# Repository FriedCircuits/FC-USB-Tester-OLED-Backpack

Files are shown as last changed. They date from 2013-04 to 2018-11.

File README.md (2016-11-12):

FC-USB-Tester-OLED-Backpack
===========================
This is the source code for the USB Tester OLED Backpack 

Which can be found at:
https://friedcircuits.us/tools/46

To compile this code you will need the following libraries:
===========================
Old Version

[Adafruit GFX](https://github.com/adafruit/Adafruit-GFX-Library)

[Adafruit SSD1306](https://github.com/adafruit/Adafruit_SSD1306)

2.0

Needs [UG8LIB] (https://github.com/olikraus/u8glib)

Both Versions

[TimerOne](https://github.com/PaulStoffregen/TimerOne)

[ClickButton](http://code.google.com/p/clickbutton/)

[Adafruit INA219](https://github.com/adafruit/Adafruit_INA219)

Download ZIP in each version folder for a working set with libraries and configuration of hardware SPI and display size

Use the new firmware version with the new Java app

https://github.com/FriedCircuits/FC-USB-Tester-Data-Logger-App

There may be a bug that shifts the display. We are working on a solution - Testing a new library for the display.

How to update firmware:

http://friedcircuits.us/docs/oled-backpack-how-to-update-firmware/

License: All source code and designs are released under 

Creative Commons NonCommercial-ShareAlike 

CC BY-NC-SA



Please contact me for commercial opportunities.

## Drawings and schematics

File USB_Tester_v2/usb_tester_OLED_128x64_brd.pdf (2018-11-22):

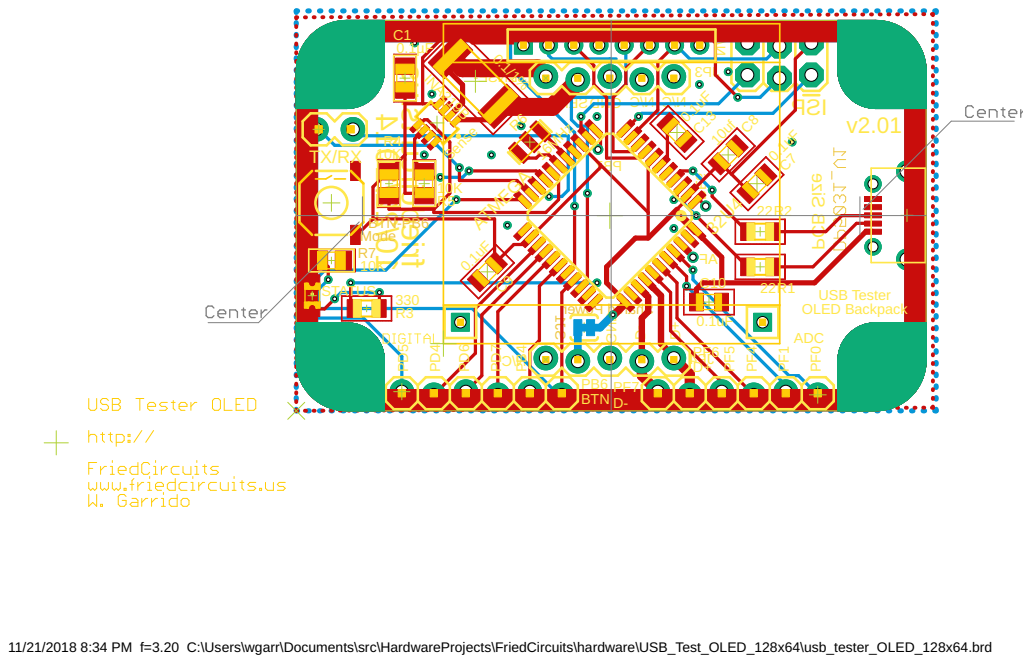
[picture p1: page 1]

11/21/2018 8:34 PM f=3.20 C:\Users\wgarr\Documents\src\HardwareProjects\FriedCircuits\hardware\USB_Test_OLED_128x64\usb_tester_OLED_128x64.brd

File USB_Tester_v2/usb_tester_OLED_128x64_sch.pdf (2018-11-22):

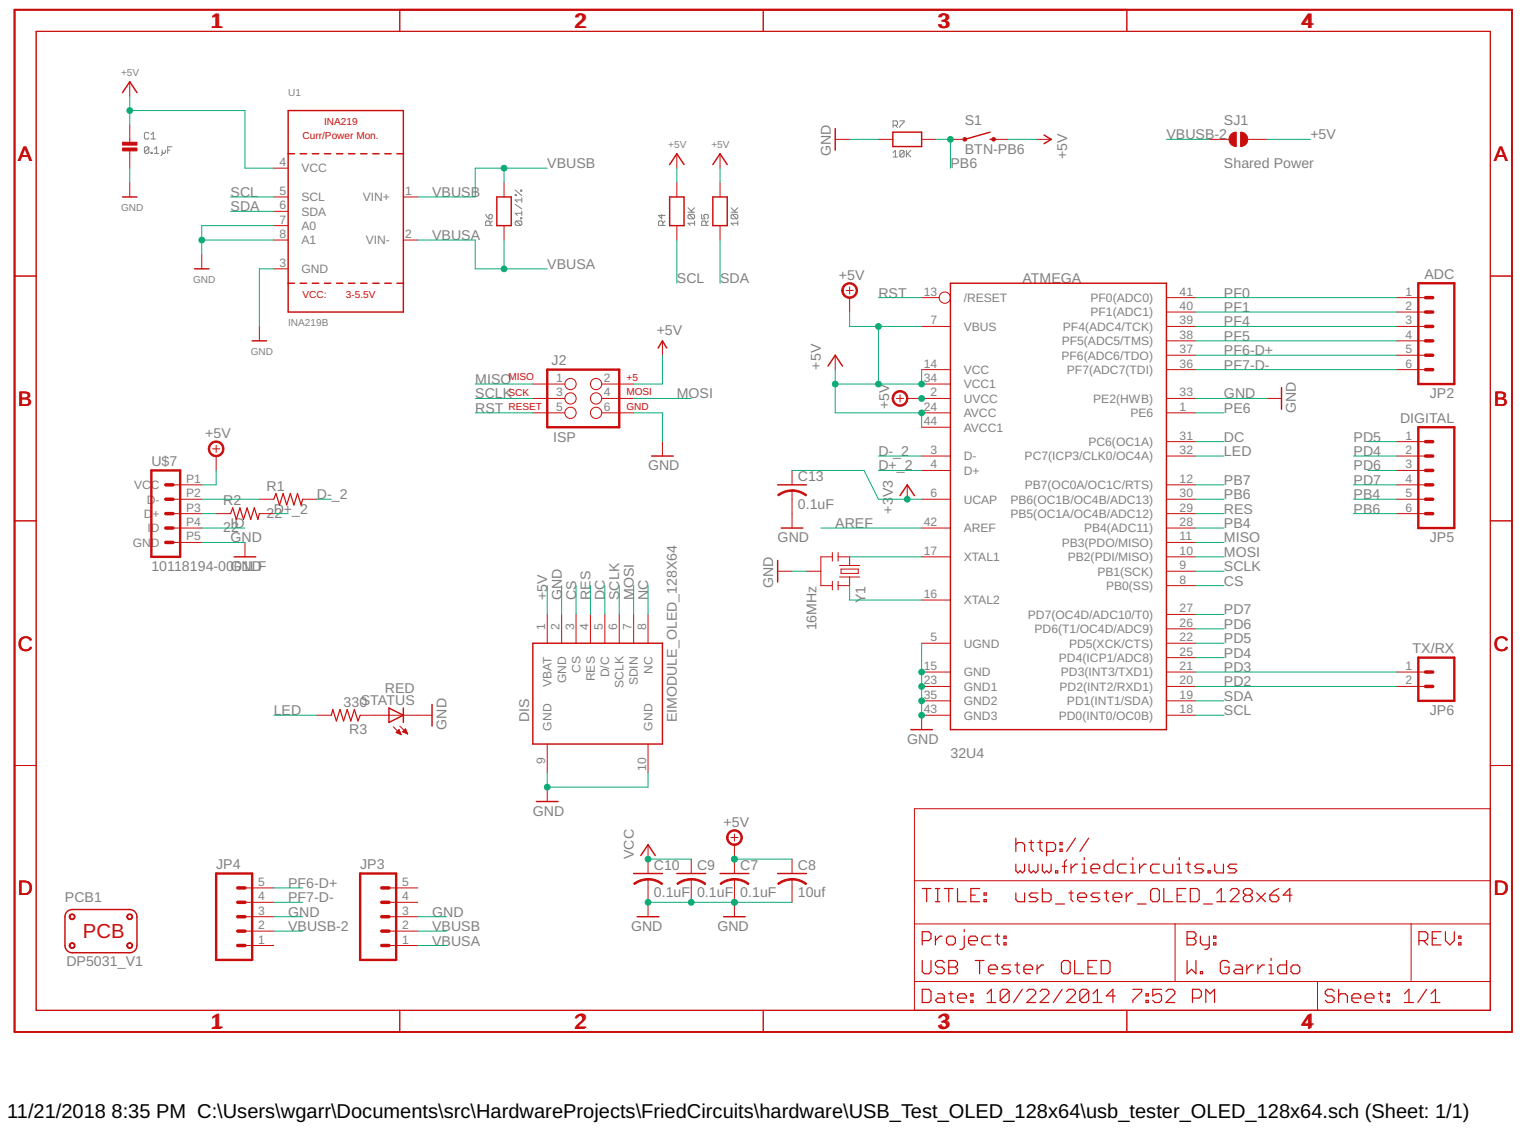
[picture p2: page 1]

11/21/2018 8:35 PM C:\Users\wgarr\Documents\src\HardwareProjects\FriedCircuits\hardware\USB_Test_OLED_128x64\usb_tester_OLED_128x64.sch (Sheet: 1/1)

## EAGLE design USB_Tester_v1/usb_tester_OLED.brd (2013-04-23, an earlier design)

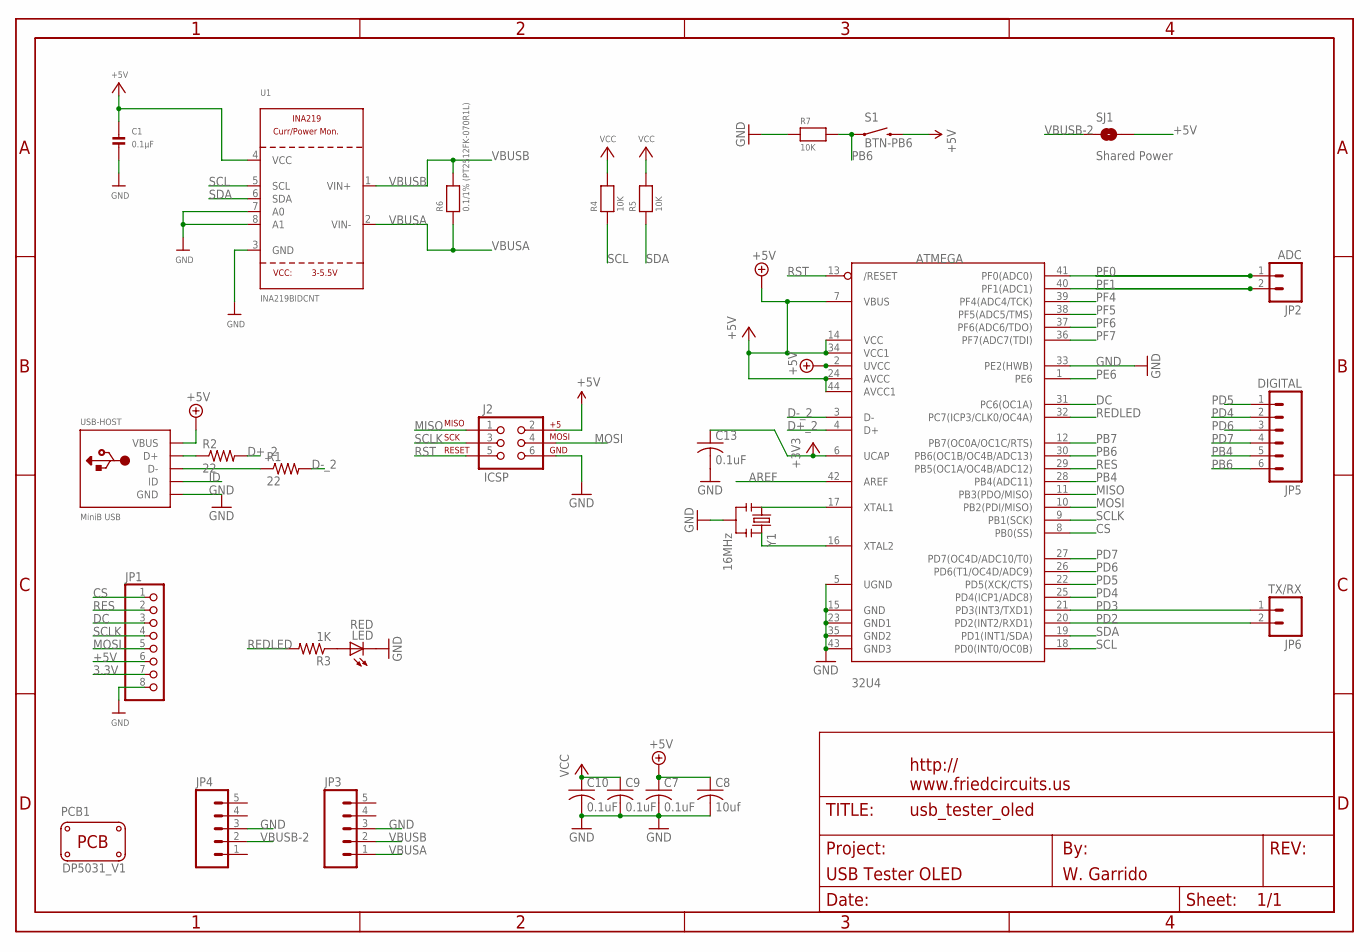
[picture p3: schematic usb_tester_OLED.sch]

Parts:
32U4: ATMEGA; TQFP44
C1: 0.1µF; 0805
C7, C9, C10, C13: 0.1uF; C0805K
C8: 10uf; C0805K
J2: ICSP; 2X3_LOCK
JP1: HEADER-1X876MIL; 1X08_ROUND_76
JP2: ADC; 1X02_LOCK
JP3, JP4: M05LOCK; 1X05_LOCK
JP5: DIGITAL; 1X06_LOCK
JP6: TX/RX; 1X02_LOCK
LED: RED; CHIPLED_0805
PCB1: PCB_DP_RECTANGLE-31X50; DP5031_V1
R1, R2: 22; R0805
R3: 1K; R0805
R4, R5, R7: 10K; 0805
R6: 0.1/1% (PT2512FK-070R1L); 2512
S1: BTN-PB6; TACTILE_SWITCH_SMD
SJ1: Shared Power; SJ_2S-TRACE
U1: INA219BIDCNT; SOT23-8
U$1: FRAME_DINA4_L; FC_CREDIT
USB-HOST: MiniB USB; USB-MINIB
Y1: 16MHz; RESONATOR-SMD

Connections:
3.3V: JP1.7
+3V3: 32U4.6 (UCAP), C13.1
+5V: 32U4.2 (UVCC), 32U4.7 (VBUS), 32U4.14 (VCC), 32U4.24 (AVCC), 32U4.34 (VCC1), 32U4.44 (AVCC1), C1.1, C7.1, C8.1, C9.1, C10.1, J2.2, JP1.6, R4.2, R5.2, S1.3 (2), SJ1.2, U1.4 (VCC), USB-HOST.VBUS
AREF: 32U4.42 (AREF)
CS: 32U4.8 (PB0(SS)), JP1.1
D+_2: 32U4.4 (D+), R2.2
D-_2: 32U4.3 (D-), R1.2
DC: 32U4.31 (PC6(OC1A)), JP1.3
GND: 32U4.5 (UGND), 32U4.15 (GND), 32U4.23 (GND1), 32U4.33 (PE2(HWB)), 32U4.35 (GND2), 32U4.43 (GND3), C1.2, C7.2, C8.2, C9.2, C10.2, C13.2, J2.6, JP1.8, JP3.3, JP4.3, LED.C, R7.1, U1.3 (GND), U1.7 (A0), U1.8 (A1), USB-HOST.GND, Y1.2
ID: USB-HOST.ID
MISO: 32U4.11 (PB3(PDO/MISO)), J2.1
MOSI: 32U4.10 (PB2(PDI/MISO)), J2.4, JP1.5
unnamed: LED.A, R3.1
unnamed: R2.1, USB-HOST.D+
unnamed: R1.1, USB-HOST.D-
unnamed: 32U4.17 (XTAL1), Y1.1
unnamed: 32U4.16 (XTAL2), Y1.3
PB4: 32U4.28 (PB4(ADC11)), JP5.5
PB6: 32U4.30 (PB6(OC1B/OC4B/ADC13)), JP5.6, R7.2, S1.1
PB7: 32U4.12 (PB7(OC0A/OC1C/RTS))
PD2: 32U4.20 (PD2(INT2/RXD1)), JP6.2
PD3: 32U4.21 (PD3(INT3/TXD1)), JP6.1
PD4: 32U4.25 (PD4(ICP1/ADC8)), JP5.2
PD5: 32U4.22 (PD5(XCK/CTS)), JP5.1
PD6: 32U4.26 (PD6(T1/OC4D/ADC9)), JP5.3
PD7: 32U4.27 (PD7(OC4D/ADC10/T0)), JP5.4
PE6: 32U4.1 (PE6)
PF0: 32U4.41 (PF0(ADC0)), JP2.1
PF1: 32U4.40 (PF1(ADC1)), JP2.2
PF4: 32U4.39 (PF4(ADC4/TCK))
PF5: 32U4.38 (PF5(ADC5/TMS))
PF6: 32U4.37 (PF6(ADC6/TDO))
PF7: 32U4.36 (PF7(ADC7(TDI))
REDLED: 32U4.32 (PC7(ICP3/CLK0/OC4A)), R3.2
RES: 32U4.29 (PB5(OC1A/OC4B/ADC12)), JP1.2
RST: 32U4.13 (/RESET), J2.5
SCL: 32U4.18 (PD0(INT0/OC0B)), R4.1, U1.5 (SCL)
SCLK: 32U4.9 (PB1(SCK)), J2.3, JP1.4
SDA: 32U4.19 (PD1(INT1/SDA)), R5.1, U1.6 (SDA)
VBUSA: JP3.1, R6.1, U1.2 (VIN-)
VBUSB: JP3.2, R6.2, U1.1 (VIN+)
VBUSB-2: JP4.2, SJ1.1

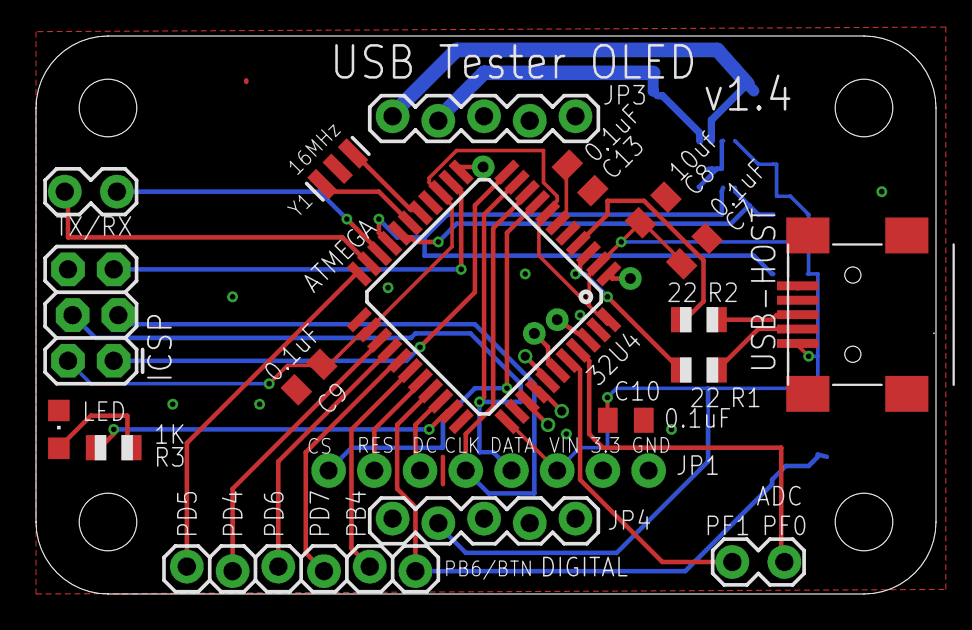
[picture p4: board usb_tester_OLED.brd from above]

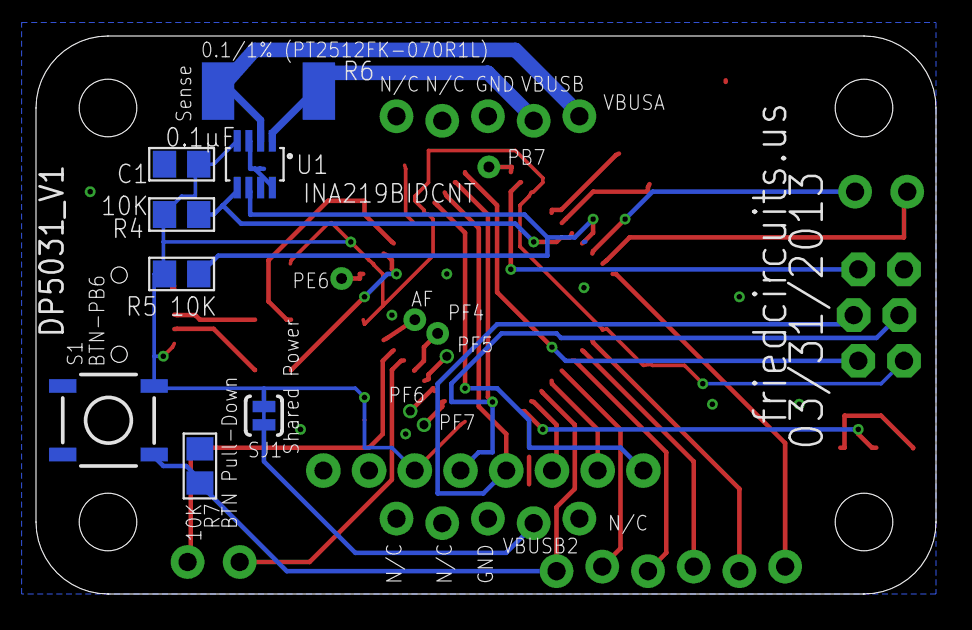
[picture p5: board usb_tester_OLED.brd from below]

Board: 2 copper layers, 50.0 x 31.0 mm, 29 parts (8 on the bottom side), 33 nets.

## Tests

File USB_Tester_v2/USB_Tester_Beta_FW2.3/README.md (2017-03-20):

FC-USB-Tester-OLED-Backpack
===========================
This is the beta firmware v2.2 for the USB Tester OLED Backpack. 

Can be found at:
https://friedcircuits.us/tools/46

New Features
===========================
Beta FW 2.2
* Cleaned up old code and added comment block to every function
* Added run timer, thanks to WeisTekEng
* Events Trigger serial notification of start and end of threshold and percent change
* Ability to save settings to EEPROM
* Ability to disable display for long term logging to save on wear
* New Commmands
	* E:0 - Disable events
	* E:1 - mA Threshold trigger - start and end uses existing W: command to set mA threshold
	* E:2 - Single percent changed
	* P:XXX - Set percent changed trigger
	* C:0 - Output current saved settings
	* C:1 - Load saved settings
	* C:2 - Save settings
	* C:3 - Output running settings
	* D:0 - Disable display
	* D:1 - Enable display

Hold button during boot to disable loading settings from EEPROM. 

Beta FW 2.3 - Code review help from @PhilipFreidin from fliptronics.com
* Increase sample speed default to 1kHz! This is a biggy feature, made possible by the following optimizations
* Increase I2C clock to 800kHz from 100kHz
* USB D+/- ADC uses int and ADC clock set to 250khz, a bit past recommended of 200khz
* Removed F() to free up flash and should be faster but uses 14% more RAM
* Fixed drawEnergy, wasn't using printjustifed2 so was rounding and displaying .00
* Using accumulators in readADC ISR and calculate in main loop mAh, mWh and current/voltage avg
* Optimize graph draw by moving mapping of values to drawGraph
* Optimize map function
* Reduce use of floats
* Libraries now included in source folder for portablity and customization of libraries
* Allow faster serial rate
* 2.31 fixed mAh/mWh calculations
* 2.32 optimized mAh/mWh calculations and var clean up
* TODO: Handle negative current for monitoring battery charging. 

28236 Bytes used
  436 Bytes free

Uses the following libraries:
===========================

[UG8LIB] (https://github.com/olikraus/u8glib)

[TimerOne](https://github.com/PaulStoffregen/TimerOne)

[ClickButton](http://code.google.com/p/clickbutton/)

[Adafruit INA219](https://github.com/adafruit/Adafruit_INA219)

[EEPROMex] (https://github.com/thijse/Arduino-EEPROMEx)

Firmware can be used with Wizkers.io 

Firmware Update
==============================

Wizkers.io - Download and select hex from Intrument Upgrade under settings.

Hex can be loaded with AVRDUDE as well. 

Arduino IDE: http://friedcircuits.us/docs/oled-backpack-how-to-update-firmware/

License: All source code and designs are released under 

Creative Commons NonCommercial-ShareAlike 

CC BY-NC-SA



Please contact me for commercial opportunities.

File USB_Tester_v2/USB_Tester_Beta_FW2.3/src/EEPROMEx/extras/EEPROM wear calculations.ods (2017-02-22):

EEPROM wear calculations
We will assume | 100,000 | write/erase cycles
From livetime to writes /second
If we want our EEPROM to live for | 100 | years
we could write | 1000 | times per cell per year
which is equal to | 2.74 | times per cell per day
which is equal to | 0.11 | times per cell per hour
which is equal to | 0.002 | times per cell per minute
which is equal to | 0.0000 | times per cell per second
From spread to writes/ second
However, if we spread a byte over | 200 | cells
we can write this byte | 22.83 | times per hour
which is equal to | 0.38 | times per minute
From time / write to livetime
We want to write once per | 1.000 | millisec
we could write for | 100000 | seconds
which is equal to | 1666.67 | minutes
which is equal to | 27.78 | hours
which is equal to | 1.157 | Days

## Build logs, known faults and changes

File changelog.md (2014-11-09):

FC-USB-Tester-OLED-Backpack
===========================
v2.10
-Start of changelog

-Switch to UG8Lib display library

-Clean up Energy and Peak\Mins screens

-Updated large font screens with bar graphs that auto scale

-Added firmware version with serial command

Note: Java app v1.0+ can check for new versions of the firmware from github

License: All source code and designs are released under 

Creative Commons NonCommercial-ShareAlike 

CC BY-NC-SA



Please contact me for commercial opportunities.

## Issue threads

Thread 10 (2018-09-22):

Auto reset when plug in DUT

gyboy, 2018-09-22:
hi, I have to say this tool is so useful,but I found some problems when using it, usually when the the dut was pluged in the deviceafter it had power on(especially comsumes heavy current), the device will auto reset while I can see the boot led is breath and then display the first page. I have confirmed that it was not made by the voltage dropped down, I doubted that mabye the usb data line influenced the mcu while I did not found any influence inthe code,I do not know how to solve it,can you give me some advice,ths.

FriedCircuits, 2018-11-22:
Hi,
Sorry for the delay in getting back to you. I have seen this issue from time to time and never figured out what it was. Something is triggering the ATmega32u4 to enter the bootloader. I know that the way the bootloader is usually entered is to open the serial port at 1200 baud and then disconnect and reconnect to reprogram.  I thought it would be due to voltage drop but as you said it doesn't seem to be so.  What I have noticed it doesn't seem to do it twice in a row just the first time. So really strange.

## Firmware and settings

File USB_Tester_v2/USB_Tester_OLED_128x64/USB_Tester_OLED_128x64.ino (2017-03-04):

/*************************************
USB Tester OLED Display - v1.2
Created by: William Garrido
Created: 01/10/2013
This displays the current and voltage from the USB Tester to the OLED display using the OLED Backpack
Also sends data to serial port for data logging via Java app
Kits are aviaible at www.tindie.com and more info can be found on www.friedcircuits.us

Changelog by Edouard Lafargue

2013.04.11
- Autoscroll of graph

ToDo:
- Remove shunt voltage and load voltage display (are those really necessary ?)
- Autoscale of graph

-William Garrido
2013.08.17
-Removed SVolt and BVolt
-Moved Current\Volt under graph
-Extend graph width of display
-Use clearDisplay to speed up redraws
-Reduce logo display time
-Enabled button to cycle display speed
-Millis based delay

2013.08.27 - Edouard Lafargue
- Add simple graph autoscale (500mA, 1A, 1.5A, 2A, 5A)

2013.08.29 - Edouard Lafargue
- Use TimerOne interrupts to read values at a fixed rate, so that
  we can energy consumption
- New feature: multiple screens (ongoing)

2013.08.30 - Edouard Lafargue
- Display mA without decimal points

2013.09.09 - William Garrido
-Added decimal to lower display
-Top display auto adjust if decimal needed
-Turned off debug by default
-Long press clears peaks and energy usage

2013.09.10 - William Garrido
-Added system display message handling with display time
-Added Reset message
How to use setMsg()
Call setMsg(Message, time to display)
-Remove decimal due to inacurrate, IC is .8mA resolution
-fixed which voltage var for peak current tracking
-fixed min voltage\current reset

2013.09.11 - William Garrido
-Rewrote button function using ClickButton library from 
http://code.google.com/p/clickbutton/wiki/Usage
Fixes screen changing when reseting, 
so action happens after button is let go
-Added 2nd printJustified function for decimal
-Now mWh and mAh use decimals

2013.11.10 - Ed Lafargue
- Add support for basic serial commands
- Keep graph memory as unsigned ints instead of floats, saves 256 bytes in memory!

2014.01.12 - William Garrido
- Improve D-\+ Analog readings by using internal 1.1v ref and dividing by 1023 instead of 1024
- Split energy readings to multiple lines to take use of larger display and give room for larger readers

2014-10-10 - William Garrido
- Switch to UG8Lib for graphics handling
- Split update scope function, only updates graph. Graph data updates is outside picture loop.
- Spilt message handling so that variables are updated outside picture loop.
- Clean up code
- Added command to get firmware version

2014-11-10-2014 - William garrido
-Re-enable device name on startup
-Add firmware version to display startup
**************************************/

#include <Wire.h>
#include <SPI.h>
#include <Adafruit_INA219.h>
#include <U8glib.h>
#include <TimerOne.h>
#include <ClickButton.h>

#define FW_VERSION 2.11

// All hardware pin usage is defined here:
//#define OLED_DC 5
//#define OLED_CS SS
//#define OLED_CLK SCK
//#define OLED_MOSI MOSI
//#define OLED_RESET 9
#define LEDPIN 13
#define BTN_PIN 10
//USB Data Lines
#define USB_DP A1
#define USB_DM A0

// Define two set/clear macros to do PIN manipulation
// way way faster than Arduino's digitalWrite.
// inspired by the the _BV() macro
#define setpin(port, pin) (port) |= (1 << (pin)) 
#define clearpin(port, pin) (port) &= ~(1 << (pin))

#define DEBUG 0

uint16_t ledWarn = 400; //Threshold in mA

// Graph values:
// Graph area is from 0 to 127
#define GRAPH_MEMORY 128
// We store the values as unsigned 16 bit integers (0 to 65535), rather than floats,
// so that our array is only 256 bytes long, instead of 512 (floats are 32bits).
uint16_t graph_Mem[GRAPH_MEMORY];
uint8_t ring_idx = 0; // graph_Mem is managed as a ring buffer.

// Autoscale management
uint16_t autoscale_limits[] = {100, 200, 500, 1000, 1500, 2500, 3200}; // in mA
uint8_t autoscale_size = sizeof(autoscale_limits) / sizeof(uint16_t);
uint8_t graph_MAX = 0; // Max scale by default
float autoscale_max_reading = 0;  // The memorized maximum reading over the window
uint8_t autoscale_countdown = GRAPH_MEMORY;

//Button
ClickButton modeBtn(BTN_PIN, HIGH);

// Serial input buffer
#define INPUT_BUFFER_SIZE 16
char input_Buffer[INPUT_BUFFER_SIZE];
uint8_t input_Buffer_Index;

// Serial output management
unsigned long lastOutput = 0;
uint16_t serialOutputRate = 1000;

// On-screen output
unsigned long lastDisplay = 0;

//Current Sensor
Adafruit_INA219 ina219;

uint16_t OLED_REFRESH_SPEED = 100; //Startup refresh delay

uint8_t graphX = 0; //Start of X for graph
uint8_t graphY = 0;  //y placement of graph

//Init OLED Display
//Adafruit_SSD1306 display(OLED_MOSI, OLED_CLK, OLED_DC, OLED_RESET, OLED_CS);
U8GLIB_SSD1306_128X64 display(SS, 5, 9);
  
//FriedCircuits Logo for startup 
/*
static unsigned char FriedCircuitsUSBTester[] PROGMEM = 
{
0x00, 0x00, 0x00, 0x00, 0x00, 0x00, 0x00, 0x0F, 0x0F, 0x87, 0x87, 0xC0, 0x0C, 0x41, 0x86, 0x00,
0x00, 0x00, 0x00, 0x00, 0x00, 0x00, 0x00, 0x00, 0x00, 0x00, 0x00, 0x00, 0x0C, 0x41, 0x86, 0x00,
0x00, 0x00, 0x00, 0x00, 0x00, 0x00, 0x00, 0x00, 0x00, 0x00, 0x00, 0x00, 0x0C, 0x40, 0xCC, 0x70,
0xE1, 0xF0, 0xF0, 0xF8, 0x00, 0x00, 0x00, 0x00, 0x07, 0x00, 0x00, 0x00, 0x0C, 0x40, 0xFC, 0xF8,
0xF3, 0xF9, 0xF9, 0xFC, 0x00, 0x00, 0x00, 0x00, 0x0F, 0x80, 0x00, 0x00, 0x0C, 0x40, 0x31, 0xCC,
0x33, 0x1B, 0x1D, 0x8C, 0x00, 0x00, 0x00, 0x00, 0x18, 0xC0, 0x00, 0x00, 0x0C, 0x40, 0x01, 0x8C,
0x1A, 0x1B, 0x0D, 0x8C, 0x00, 0x07, 0xFF, 0xFF, 0xF8, 0xC0, 0x00, 0x00, 0x0C, 0x40, 0x01, 0x8C,
0x33, 0x1B, 0x99, 0x8C, 0x00, 0x1F, 0xFF, 0xFF, 0xF8, 0xC0, 0x00, 0x00, 0x0C, 0x40, 0x39, 0xFC,
0xF3, 0xF1, 0xF9, 0xF8, 0x00, 0x78, 0x00, 0x00, 0x1F, 0xC0, 0x00, 0x00, 0x0C, 0x40, 0xFC, 0xF8,
0xC0, 0xE0, 0xF0, 0x70, 0x01, 0xE0, 0x00, 0x00, 0x0F, 0x80, 0x00, 0x00, 0x0C, 0x40, 0xC6, 0x30,
0x00, 0x08, 0x00, 0x00, 0x0F, 0x80, 0x00, 0x00, 0x00, 0x00, 0x00, 0x00, 0x0C, 0x40, 0xC6, 0x30,
0x00, 0x0C, 0x00, 0x00, 0x3E, 0x00, 0x60, 0x00, 0x00, 0x00, 0x00, 0x00, 0x0C, 0x40, 0xC6, 0x30,
0x00, 0x1E, 0x00, 0x00, 0xF0, 0x01, 0xF8, 0x00, 0x00, 0x00, 0x00, 0x00, 0x0C, 0x40, 0xFE, 0x30,
0xFE, 0x1F, 0x1F, 0xFF, 0xC0, 0x01, 0x98, 0x00, 0x00, 0x00, 0x00, 0x00, 0x0C, 0x40, 0x7C, 0x30,
0xFE, 0x3F, 0x9F, 0xC0, 0x00, 0x00, 0x00, 0x30, 0x00, 0x00, 0x00, 0x00, 0x00, 0x00, 0x00, 0x00,
0x00, 0xBF, 0x8F, 0xBF, 0x1D, 0xF7, 0xE0, 0xF3, 0xBF, 0x06, 0x73, 0xBF, 0xF9, 0x83, 0x9C, 0x60,
0x00, 0xFF, 0xCF, 0xBF, 0xBD, 0xF7, 0xF9, 0xF7, 0xBF, 0x9E, 0xF3, 0xFF, 0xFF, 0x83, 0xDD, 0xF0,
0x00, 0xFF, 0xCE, 0x3F, 0xBD, 0xC7, 0xFB, 0xC7, 0xBF, 0xBE, 0xF3, 0xFB, 0xFF, 0x83, 0xDF, 0xE0,
0x00, 0xFF, 0xCF, 0xBF, 0xBD, 0xF7, 0xBB, 0x87, 0xBF, 0xB8, 0xF3, 0xF9, 0xCF, 0xC3, 0xDD, 0xF0,
0x00, 0xFF, 0xCF, 0xBF, 0xBD, 0xF7, 0xBF, 0x87, 0xBF, 0x78, 0xF7, 0x79, 0xC3, 0xC3, 0xDC, 0xF0,
0x02, 0xFF, 0xCE, 0x3F, 0xFD, 0xF7, 0xFB, 0xF7, 0xBF, 0xBE, 0x7F, 0x79, 0xC7, 0xDB, 0xFD, 0xF0,
0x06, 0xFF, 0xBE, 0x3D, 0xFD, 0xFF, 0xE3, 0xFF, 0xBB, 0xBF, 0x7F, 0x79, 0xC7, 0xB9, 0xF9, 0xE0,
0x03, 0x7F, 0x7E, 0x19, 0x99, 0xFF, 0x80, 0xFB, 0xB9, 0x8F, 0x3C, 0x39, 0xC6, 0x18, 0xF1, 0xC0,
0x03, 0xFC, 0x00, 0x00, 0x00, 0x7F, 0x07, 0xE0, 0x00, 0x00, 0x1C, 0x0C, 0x0C, 0x40, 0x18, 0x30
};
*/
// Voltages are now read in the interrupt routine, and available in
// global (volatile because modified within an interrupt) variables:
volatile float shuntvoltage = 0;
volatile float busvoltage = 0;
volatile float current_mA = 0;
volatile float loadvoltage = 0;
volatile float milliwatthours = 0;
volatile float milliamphours = 0;

// Serial data lines:
volatile float dpVoltage = 0;
volatile float dmVoltage = 0;

// Keep track of peak/min significant values:
volatile float peakCurrent = 0;
volatile float voltageAtPeakCurrent = 0;
volatile float minVoltage = 10;
volatile float currentAtMinVoltage = 0;
// (no need, we can compute it) volatile float peakPower = 0;
volatile float voltageAtPeakPower = 0;
volatile float currentAtPeakPower = 0;

// Keep track of variation of volts/amps over the serial refresh period
volatile float rpPeakCurrent = 0;
volatile float rpMinCurrent = 0;
volatile float rpPeakLoadVolt = 0;
volatile float rpMinLoadVolt = 0;
volatile float rpAvgCurrent = 0;
volatile float rpAvgLoadVolt = 0;
uint32_t rpSamples = 1;



// Global defines for polling frequency:
#define READFREQ 100000 // in microseconds

// Multiple screen support
uint8_t current_screen = 0;
#define MAX_SCREENS  6;

//Display message handling
unsigned int setDisplayTime = 0;
char setMsgDisplay[10];
uint8_t oldScreen = 0;
bool msgDisplay = false;
#define MSGSCREEN 6;

//Track message display time, made global instead of static so that it is not updated during picture loop
uint8_t msgTime = 0;

/**
 * Initialisation of the sketch
 */
void setup()
{

  pinMode(LEDPIN, OUTPUT);
  digitalWrite(LEDPIN, HIGH);
  
  //Setup button times
  modeBtn.debounceTime   = 20;   // Debounce timer in ms
  modeBtn.multiclickTime = 250;  // Time limit for multi clicks
  modeBtn.longClickTime  = 2000; // time until "held-down clicks" register

  
  Serial.begin(115200);
  //Serial.println(F("USB Tester OLED Backup Online"));
   
  //Init current sensor
  ina219.begin();
  
  //by default, we'll generate the high voltage from the 3.3v line internally! (neat!)
  //display.begin(SSD1306_SWITCHCAPVCC);
  
  //Setup display
  //display.setTextSize(1);
  display.setFont(u8g_font_6x12);
  //display.setTextColor(WHITE);
  display.setColorIndex(1);
 
  // Initialize ring buffer
  for (uint8_t i=0; i < GRAPH_MEMORY; i++) {
    graph_Mem[i] = 0;
  }

  display.firstPage();
  do {
   display.drawStr( 2, 10, "USB Tester 2.0");
   display.drawStr( 5, 20, "FriedCircuits.us");
   display.drawStr( 5, 30, "Firmware Version");
   display.setPrintPos(5,40);
  display.print(FW_VERSION);
  }while( display.nextPage());
  delay(2000);
  digitalWrite(LEDPIN, LOW);

  Timer1.initialize(READFREQ); // 100ms reading interval
  Timer1.attachInterrupt(readADCs); 
}

/**
 * This is where we do the reading of voltage & current. Should be kept as short
 * as possible, of course. our sampling period is 100ms
 */
void readADCs() {
  // TODO: check exact length of this interrupt routine on the scope using
  // a signal line...
#ifdef DEBUG
      setpin(PORTD,5);  // Just a debug signal for my scope to check
                        // how long it takes for the loop below to complete
#endif
  
  sei(); // re-enable interrupts since the ina219 functions need those.
         // in practice, we're doing nested interrupts, gotta be careful here...
  shuntvoltage = ina219.getShuntVoltage_mV();
  busvoltage = ina219.getBusVoltage_V();
  current_mA = ina219.getCurrent_mA();
  loadvoltage = busvoltage + (shuntvoltage / 1000);
  milliwatthours += busvoltage*current_mA*READFREQ/1e6/3600; // 1 Wh = 3600 joules
  milliamphours += current_mA*READFREQ/1e6/3600;
  
  // Update peaks, min and avg during our serial refresh period:
  if (current_mA > rpPeakCurrent)
      rpPeakCurrent = current_mA;
  if (current_mA < rpMinCurrent)
      rpMinCurrent = current_mA;
  if (loadvoltage > rpPeakLoadVolt)
      rpPeakLoadVolt  = loadvoltage;
  if (loadvoltage < rpMinLoadVolt)
      rpMinLoadVolt = loadvoltage;
  rpAvgCurrent = (rpAvgCurrent*rpSamples + current_mA)/(rpSamples+1);
  rpAvgLoadVolt = (rpAvgLoadVolt*rpSamples + loadvoltage)/(rpSamples+1);
  rpSamples++;
  
  // Update absolute peaks and mins
  if (current_mA > peakCurrent) {
      peakCurrent = current_mA;
      voltageAtPeakCurrent = loadvoltage;
  }
  
  if (loadvoltage < minVoltage) {
      minVoltage = loadvoltage;
      currentAtMinVoltage = current_mA;
  }
  
  // TODO: check if we gain time by using a peakPower variable ?
  if ( (voltageAtPeakPower*currentAtPeakPower) < (loadvoltage*current_mA)) {
      voltageAtPeakPower = loadvoltage;
      currentAtPeakPower = current_mA;
  }
  
#ifdef DEBUG
      clearpin(PORTD,5);  // Just a debug signal for my scope to check
                        // how long it takes for the loop below to complete
#endif
}


/**
 * This is the display loop and button handler
 */
void loop()
{
  //display.firstPage();
  modeBtn.Update();  
  unsigned long now = millis();

  // Refresh Display  
  if (now - lastDisplay > OLED_REFRESH_SPEED){
    
    // No need to read those inside the interrupt, those are not
    // time-sensitive
    double vcc = readVcc()/1000.0;
    dpVoltage = analogRead(USB_DP) * vcc / 1023;
    dmVoltage = analogRead(USB_DM) * vcc / 1023;

   //Refresh graph from current sensor data
    drawGraph(current_mA);
    //update msg outside picture loop before next display refresh
    if(current_screen == 6){
      if (msgTime <= setDisplayTime){
      msgTime++;
      }
      else {
        current_screen = oldScreen;
        msgTime = 0;
        msgDisplay=false;
      }
    }

    display.firstPage();
	do{
    switch (current_screen) {
      case 0:
        drawScope();
        break;
      case 1:
        drawEnergy();
        break;
      case 2:
         drawPeakMins();
         break;
      case 3:
         drawBig((current_mA*loadvoltage)/1000, "W",2);
         break;
      case 4:
         drawBig(current_mA, "mA",0);
         break;
      case 5:
         drawBig(loadvoltage, "V",2);
         break;
      case 6: //This is a special screen only called within the sketch to take over display with user message
         drawMsg();
         break;
      default:
        drawScope();
    }
    
    drawBottomLine();
	} while (display.nextPage() );
    lastDisplay = now;
  }

  // Output on serial port
  if (now - lastOutput > serialOutputRate) {
    serialOutput();
    // Reset sampling period:
    rpPeakCurrent = 0;
    rpMinCurrent = current_mA;
    rpPeakLoadVolt = 0;
    rpMinLoadVolt = loadvoltage;
    rpAvgCurrent = current_mA;
    rpAvgLoadVolt = loadvoltage;
    rpSamples = 1;

    lastOutput = now;
  }

  // Check if we have serial input
  while (Serial.available()) {
    input_Buffer[input_Buffer_Index] = Serial.read();
    if (input_Buffer[input_Buffer_Index] == '\n') {
      input_Buffer[input_Buffer_Index] = 0;
      processInput();
      input_Buffer_Index = 0;
    } else 
      input_Buffer_Index = (input_Buffer_Index+1)%INPUT_BUFFER_SIZE;
  }

  uint8_t btnState = digitalRead(BTN_PIN);
  
  if ((current_mA >= ledWarn) || (btnState)){
    digitalWrite(LEDPIN, HIGH);
  }
  else {
     digitalWrite(LEDPIN, LOW);
  }

  if (modeBtn.clicks != 0) setButtonMode(modeBtn.clicks);

}

// Here are the commands that are supported:
//   R:XXXX where XXXX is a delay in miliseconds (any valid integer)
//   S:X    where X is screen number (starting at 1)
//   W:XXXX where XXXX is the warning threshold in mA for switching on the blue LED
//   Z:     reset counters

void processInput() {
  if (input_Buffer[1] != ':')
    return;
  switch (input_Buffer[0]) {
    case 'R':
      serialOutputRate = atoi(&input_Buffer[2]);
      if (serialOutputRate < 150) serialOutputRate = 150; // We sample at 100ms, so we need to remain above that value
      Serial.print(F("{ \"R\":")); Serial.print(serialOutputRate);Serial.println(F("}"));
      break;
    case 'S':
       current_screen = (input_Buffer[2]-49) % MAX_SCREENS;
       Serial.print(F("{\"S\":"));Serial.print(current_screen);Serial.println(F("}"));
       break;
    case 'Z':
       setButtonMode(-1);
       Serial.println(F("{\"Z\":\"OK\"}"));
       break;
    case 'W':
       ledWarn = atoi(&input_Buffer[2]);
       if (ledWarn > 2000) ledWarn = 2000;
       Serial.print(F("{\"W\":")); Serial.print(ledWarn);Serial.println(F("}"));
       break;
    case 'V':
       Serial.print(F("{\"V\":")); Serial.print(FW_VERSION);Serial.println(F("}"));
    default:
      break;
  }
}


void drawBottomLine() {
  //Set x,y and print sensor data
  display.setPrintPos(0,64);
  display.print(loadvoltage);   display.print(F("V "));
  printJustified(current_mA);   display.print(F("mA "));
  //display.print((current_mA*loadvoltage)/1000);  display.print("W");  
  printJustified2((current_mA*loadvoltage)/1000, 2); display.print("W"); 
}

// Our various screens:
void drawScope() {

  for (uint8_t i=0; i < GRAPH_MEMORY; i++) {
    uint8_t val = 54 - map(graph_Mem[(i+ring_idx)%GRAPH_MEMORY], 0, autoscale_limits[graph_MAX], 0, 54);
    display.drawPixel(i, val);
  }
  
  // Display current scale
  // Note: commented out, not quite sure this is very important since
  // the graph is merely a trend indicator - we only have 24 pixels after
  // all
  display.setPrintPos(104,7);
  display.print((autoscale_limits[graph_MAX]+0.0)/1000);
}

// Draw current energy values and peak
// power
void drawEnergy() {
  display.setPrintPos(28,7);
  display.print(F("Energy Usage"));
  display.drawHLine(0,7,128);
  display.setPrintPos(0,17);
  printJustified2(milliwatthours,2);
  display.print(F("mWh "));
  display.setPrintPos(64,17);
  printJustified2(milliamphours,2);
  display.print(F("mAh"));

  display.setPrintPos(0,32);
  display.print(F("Peak: "));
  display.print(voltageAtPeakPower*currentAtPeakPower/1000);
  display.print("W");
  display.setPrintPos(0,40);
  display.print(F("@ "));
  display.print(voltageAtPeakPower);
  display.print(F("V & "));
  display.print(currentAtPeakPower);
  display.print(F("mA"));
  
  display.drawHLine(0,53,128);

}


// Displays peak and minimum values
void drawPeakMins() {
  display.setPrintPos(28,7);
  display.print(F("Peak - Mins"));
  display.drawHLine(0,7,128);
  display.setPrintPos(0,17);
  display.print(F("Peak:"));
  printJustified(peakCurrent);
  display.print(F("mA ("));
  display.print(voltageAtPeakCurrent);
  display.print(F("V) "));
  display.setPrintPos(0,32);
  display.print(F("Min:"));
  display.print(minVoltage);
  display.print(F("V ("));
  display.print(currentAtMinVoltage);
  display.print(F("mA)"));
  
  display.drawHLine(0,53,128);

}

// Displays one big value & unit, with X number of decimals
// Display width is 7 digits wide, we leave the 2 rightmost digits
// for unit display
void drawBig(float val, char* unit, uint8_t decimals) {
  display.setPrintPos(50,16);
  display.setFont(u8g_font_10x20);
  if ((decimals < 2) && (val < 1000)) display.print(" ");
  if ((decimals < 1) && (val < 10000)) display.print(" ");
  if (val < 100) display.print(" ");
  if (val < 10) display.print(" ");
  display.print(val, decimals);
  display.print(unit);
  display.setFont(u8g_font_6x12);
  
  
  display.drawRFrame(0,24,128,20,1);
  float limit = 0.0;
  if(unit == "W"){
    display.setPrintPos(0,7);
    display.print(F("Peak:"));
    display.setPrintPos(0,16);
    display.print(voltageAtPeakPower*currentAtPeakPower/1000);
    display.print("W");
    
    float wattMax = 1.10;
    if(val > 10.10){limit = 0.201; wattMax = 25.10;}
    else if (val > 1.10){limit = 0.041; wattMax = 5.10;}
    else{limit = 0.009;} //1W range
    for(int x = 2; x <= 126; x++){
      if ((float)x <= ((float)val/limit)){display.drawVLine(x,26,16);}  
    }
    //display.drawVLine((voltageAtPeakCurrent/limit),26,16);
    display.drawVLine(0,44,8); 
    display.setPrintPos(1,52); display.print(F("0"));
    display.drawVLine(64,44,8);
    display.setPrintPos(32,52); display.print(wattMax/2);  
    display.setPrintPos(97,52); display.print(wattMax);
    display.drawVLine(127,44,8); 
  }
 
  
  if(unit == "mA"){
    display.setPrintPos(0,7);
    display.print(F("Peak:"));
    display.setPrintPos(0,16);
    display.print(peakCurrent);
    display.print("mA");

    limit = (float)autoscale_limits[graph_MAX]/127; 
    for(int x = 2; x < 126; x++){
      if (x <= (val/limit)){display.drawVLine(x,26,16);}  
    }
    display.drawVLine((peakCurrent/limit),26,16);
    display.drawVLine(0,44,8); 
    display.setPrintPos(1,52); display.print(F("0"));
    display.drawVLine(64,44,8); 
    display.setPrintPos(32,52); display.print(((autoscale_limits[graph_MAX]+0.0)/1000)/2); display.print(F("A"));
    display.setPrintPos(97,52); display.print((autoscale_limits[graph_MAX]+0.0)/1000); display.print(F("A"));
    display.drawVLine(127,44,8); 
  }
  if(unit == "V"){
    display.setPrintPos(0,7);
    display.print(F("D+: "));
    display.print(dpVoltage);
    display.setPrintPos(0,16);
    display.print(F("D-: "));
    display.print(dmVoltage);
  
    float voltMax = 5.10;
    if(val > 12.10){limit = 0.21; voltMax = 26.0;}
    else if (val > 5.10){limit = 0.098; voltMax = 12.10;}
    else{limit = 0.041;} //5V range
    for(int x = 2; x <= 126; x++){
      if ((float)x <= ((float)val/limit)){display.drawVLine(x,26,16);}  
    }
    //display.drawVLine((voltageAtPeakCurrent/limit),26,16);
    display.drawVLine(0,44,8); 
    display.setPrintPos(1,52); display.print(F("0"));
    display.drawVLine(64,44,8);
    display.setPrintPos(32,52); display.print(voltMax/2);  
    display.setPrintPos(97,52); display.print(voltMax);
    display.drawVLine(127,44,8); 
  }
}

//Displays message in large font on entire display
void setMsg(char* msg, uint16_t time)
{
   if(msgDisplay == false){
     setDisplayTime = time;
     strcpy(setMsgDisplay, msg);
     msgDisplay=true;
     oldScreen = current_screen;
     current_screen=MSGSCREEN;
   }
}
void drawMsg()
{
  if (msgTime <= setDisplayTime){
  display.setPrintPos(0,16);
  display.setFont(u8g_font_10x20);
  display.print(setMsgDisplay);
  display.setFont(u8g_font_6x12);
  }
  
}
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

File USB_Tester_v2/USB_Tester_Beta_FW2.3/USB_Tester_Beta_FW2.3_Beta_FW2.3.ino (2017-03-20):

/**
  USB Tester OLED Display 
  This displays the current and voltage from the USB Tester to the OLED display using the OLED Backpack
  Also sends data to serial port for data logging via Java app
  Aviaible at https://friedcircuits.us and docs at https://learn.friedcircuits.us

  @author William Garrido
  @version 2.20
  Created: 01/10/2013

  Changelog by Edouard Lafargue
  
  2013.04.11
  - Autoscroll of graph
  
 2013.08.17 - William Garrido
  -Removed SVolt and BVolt
  -Moved Current\Volt under graph
  -Extend graph width of display
  -Use clearDisplay to speed up redraws
  -Reduce logo display time
  -Enabled button to cycle display speed
  -Millis based delay
  
  2013.08.27 - Edouard Lafargue
  - Add simple graph autoscale (500mA, 1A, 1.5A, 2A, 5A)
  
  2013.08.29 - Edouard Lafargue
  - Use TimerOne interrupts to read values at a fixed rate, so that
    we can energy consumption
  - New feature: multiple screens (ongoing)
  
  2013.08.30 - Edouard Lafargue
  - Display mA without decimal points
  
  2013.09.09 - William Garrido
  -Added decimal to lower display
  -Top display auto adjust if decimal needed
  -Turned off debug by default
  -Long press clears peaks and energy usage
  
  2013.09.10 - William Garrido
  -Added system display message handling with display time
  -Added Reset message
  How to use setMsg()
  Call setMsg(Message, time to display)
  -Remove decimal due to inacurrate, IC is .8mA resolution
  -fixed which voltage var for peak current tracking
  -fixed min voltage\current reset
  
  2013.09.11 - William Garrido
  -Rewrote button function using ClickButton library from 
  http://code.google.com/p/clickbutton/wiki/Usage
  Fixes screen changing when reseting, 
  so action happens after button is let go
  -Added 2nd printJustified function for decimal
  -Now mWh and mAh use decimals
  
  2013.11.10 - Ed Lafargue
  - Add support for basic serial commands
  - Keep graph memory as unsigned ints instead of floats, saves 256 bytes in memory!
  
  2014.01.12 - William Garrido
  - Improve D-\+ Analog readings by using internal 1.1v ref and dividing by 1023 instead of 1024
  - Split energy readings to multiple lines to take use of larger display and give room for larger readers
  
  2014-10-10 - William Garrido
  - Switch to UG8Lib for graphics handling
  - Split update scope function, only updates graph. Graph data updates is outside picture loop.
  - Spilt message handling so that variables are updated outside picture loop.
  - Clean up code
  - Added command to get firmware version
  
  2014-11-10-2014 - William garrido
  -Re-enable device name on startup
  -Add firmware version to display startup
  
  2016-06-23 - Weistek Eng | Jeremy G |
  -added UpdateTime
  -update time displays time on the energy page, allows you to kepe track of uptime.
  -Compile size 28,306 bytes (98%) only 300 bytes left make them count :)
  
  2016-10-30(2016-11-06) - William Garrido
  -Updated Reset to offset run time
  -Added event start/end handling with serial output
  -Shorten text on splash for Firmware, save flash space
  -Added event percent
  -Reduce flash size using read port
  -EEPROM for saving settings
  -Cmd to turn off display
  -Cleaned up comments and added function comment blocks

  2017-01-30 - William Garrido
  -Increase i2c clock
  -Increase default sample speed from 100000us to 5000us - Will work at 2000us but fps takes a hit.  

  2017-02-18-19 - William Garrido (Help from Philip Freidin)
  -Increase sample speed default to 1kHz! This is a biggy feature, made possible by the following optimizations
  -Increase I2C clock to 800kHz from 100kHz
  -Update macro to include pin, DEBUGSTART/END1 and DEBUGSTART/END2
  -USB D+/- ADC uses int and ADC clock set to 250khz, a bit past recommended of 200khz
  -Removed F() to free up flash and should be faster but uses 14% more RAM, currently we have plenty, might have more flash later after optimizations
  -Fixed drawEnergy, wasn't using printjustifed2 so was rounding and displaying .00
  -Using accumulators in readADC ISR and calculate in main loop mAh, mWh and current/voltage avg
  -Shrink rpSamples variable size, might need to increase later if we speed up samples
  -Optimize graph draw by moving mapping of values to drawGraph, store Y in array and map only on autoscale change. Keep another array for org values
  -Optimize map function by creating our own and only passing value to map for graph Y
  -autoscale_max_reading to uint16_t from float, graph is more general view of values anyway
  2017-02-20 - William Garido
  -Converted current to uint16 intead of float, decimal part was useless anyway. Rounded value in INA219 class
  -Converted voltage to uint16 intead of float, *0.001 when needed to make human readable for serial and OLED  
  -Fix voltage rounding issue for watt calculation due to using int16 instead of float
  -Allow faster serial rate
  -2017-03-05 - Fixed mAh,mWh calculations
  -2017-03-13 - Optimize mAh,mWh calc/var clean up   /    TODO: Handle negative current for monitoring battery charging. 
*/

#include <Wire.h>
#include <SPI.h>
#include "INA219.h"
#include "src/U8glib/U8glib.h"
#include "src/TimerOne/TimerOne.h"
#include "src/ClickButton/ClickButton.h"
#include "src/EEPROMex/EEPROMex.h"

/**
 * Firmware version
 * displayed on splach and serial with V: command
*/
#define               FW_VERSION 2.32

// All hardware pin usage is defined here:
const byte            LEDPIN = 13;
const byte            BTN_PIN = 10;
//USB Data Lines
const byte            USB_DP = A1;
const byte            USB_DM = A0;

// Define two set/clear macros to do PIN manipulation
// way way faster than Arduino's digitalWrite.
// inspired by the the _BV() macro
#define               setpin(port, pin) (port) |= (1 << (pin)) 
#define               clearpin(port, pin) (port) &= ~(1 << (pin))
#define               DEBUGSTART1 setpin(PORTD, 5)
#define               DEBUGEND1  clearpin(PORTD, 5)
#define               DEBUGSTART2 setpin(PORTD, 6)
#define               DEBUGEND2  clearpin(PORTD, 6)
#define               SETLED  setpin(PORTC, 7)
#define               CLEARLED clearpin(PORTC, 7)
//#define DEBUG 1

//Vars for handling alerts and events via LED and serial
int16_t               ledWarn = 400; //Default threshold in mA
int16_t               aPercentChange = 100; //Default percent change of current for event trigger
bool                  eventFlag = false; //Flag for tracking if event has been triggered
long                  eventTime = 0; //Time in millis event was triggered
//Set event type we are triggering on or false if no events
enum eventT {
  DISABLED = 0,
  WARN = 1, //based on set mA threshhold
  PERCENT = 2 //based on percent changed
};
eventT                  eventType = DISABLED; //Set event type, threshold, percent changed, or disabled(default)
enum eventData {
  NONE = 0, //No recent event
  START = 1, //Event start
  END = 2, //Event end
  SINGLE = 3 //Single event
};
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

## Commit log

2013-04-12 Add autoscroll for the graph
    And move the directory to an Arduino-friendly name
2013-04-22 Uncommented filter for no load
2013-04-23 Added design files in Eagle and PNG
    [usb_tester_OLED.brd, usb_tester_OLED.sch]
2013-04-27 Fixed no load filter
    [USB_Tester_OLED.ino]
2013-08-26 Redesigned display
    -Removed SVolt and BVolt
    -Moved Current\Volt under graph
    -Extend graph width of display
    -Use clearDisplay to speed up redraws
    -Reduce logo display time
    -Enabled button to cycle display speed
    -Millis based delay
    [USB_Tester_OLED.ino]
2013-08-28 Zip with fully working versions of libraries.
    Extract to Arduino folder.
2013-08-29 Lots of new features: - Now logs energy (mWh and mAh) - Multiple screens (use button to cycle)
    Displays: min Voltage, max current, mWh, mAh, peak power, along
    with relevant values at each of those points (current at min voltage,
    voltage at max current, current and voltage at peak power, etc).
    Serial output is unchanged for now, but I'll probably update this
    next.
2013-09-08 Cleanups and add a "big reading" Voltage & Current screen
2013-09-08 Fix a few typos
    [USB_Tester_OLED.ino]
2013-09-10 Added long button press to clear data
    Long button press about 3-4 seconds
    Clears all peak, min and energy usage data
2013-09-10 Updated README with need TimerOne Library
2013-09-11 Removed decimal
    Resolution of IC is .8mA
2013-09-11 Fixed min current\voltage reset
    [USB_Tester_OLED.ino]
2013-09-12 Updated button handling
    Rewrote button function using ClickButton library from
    http://code.google.com/p/clickbutton/wiki/Usage
    Fixes screen changing when reseting,
    so action happens after button is let go
    Added 2nd printJustified function for decimal
    Now mWh and mAh use decimals
    [USB_Tester_OLED.ino]
2013-12-11 Uploaded version 2 files
    [usb_tester_OLED.brd, usb_tester_OLED.sch, usb_tester_OLED_128x64.sch]
2014-01-13 Improved analogRead for D-\+
    D-\+ readings are not based on VCC instead of assumed 5v. Also split
    energy readings screen to multiple lines.
2014-11-06 Current Firmware version
    For the Java so it can check the current firmware version.
2014-11-11 Added firmware version to startup info
    [usb_tester_OLED_128x64.sch]
2014-12-21 Revert "Added firmware version to startup info"
    This reverts commit ae1a7a8cbf1ab4103c57a1c15dbe1268bf3a7579.
    [usb_tester_OLED_128x64.sch]
2014-12-21 Zip for 2.10
    [usb_tester_OLED_128x64.sch]
2016-11-12 Update TimerOne link in readme
2017-02-09 Speed up i2c
    Also fixes averging output on serial showing 0
2017-02-22 Beta Firmware 2.3 Release - 1kHz sample speed
    1kHz sample speed + optimizations
    [EEPROM wear calculations.ods]
2017-02-22 Beta Firmware 2.3 Release - 1kHz sample speed
    Updated readme
    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
2017-03-04 Fix for mAh/mWh
    Was displaying .00 instead of the value for mAh/mWh
    [USB_Tester_OLED_128x64.ino]
2017-03-05 Fixed reset of mAh/mWh Issue #9
    [USB_Tester_Beta_FW2.3_Beta_FW2.3.ino]
2017-03-06 Fixed mAh/mWh calculation issue #8
    [USB_Tester_Beta_FW2.3_Beta_FW2.3.ino]
2018-11-22 Add PDFs of board and schematic

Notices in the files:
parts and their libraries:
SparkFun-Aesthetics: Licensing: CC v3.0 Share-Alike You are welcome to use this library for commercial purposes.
